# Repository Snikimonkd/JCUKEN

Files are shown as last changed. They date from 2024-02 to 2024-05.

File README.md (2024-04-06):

# JCUKEN

Cyrillic-friendly low profile ortholinear split keyboard.

## Tools

Designed with [ergogen](https://github.com/ergogen/ergogen).

Routed with [KiCad](https://www.kicad.org/).

## Version 1

### Top view

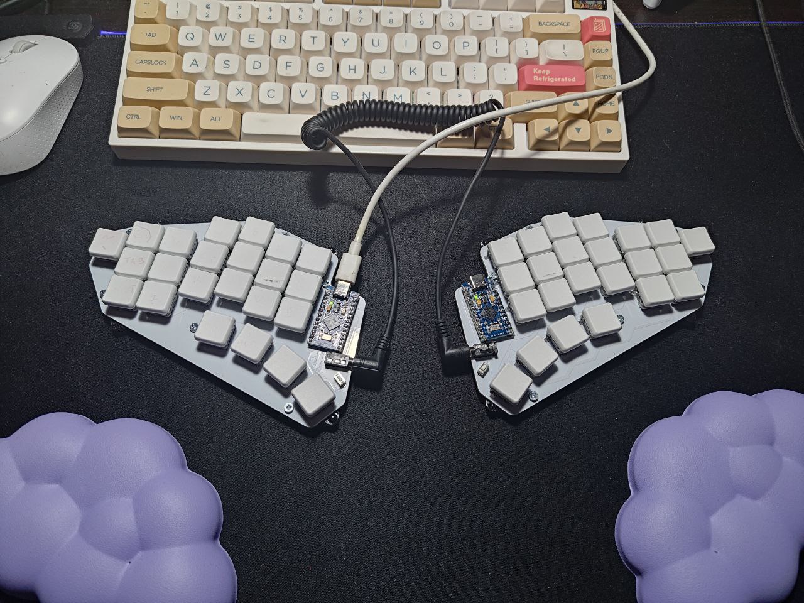
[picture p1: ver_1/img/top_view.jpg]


### Close up view

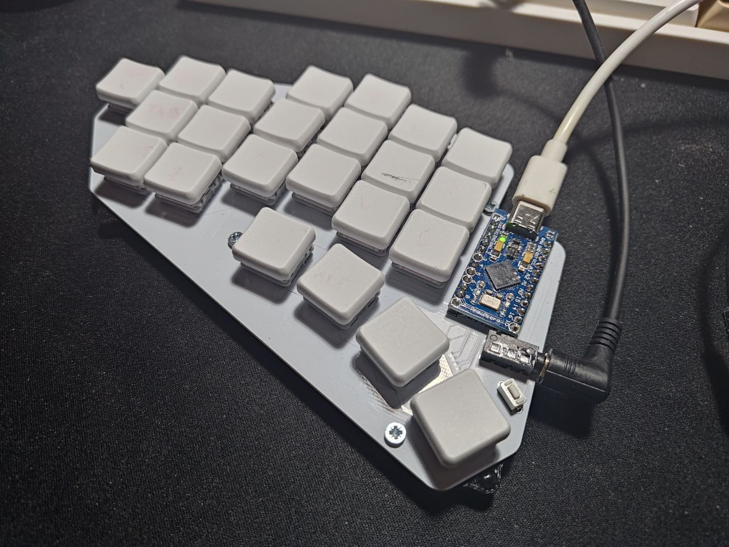
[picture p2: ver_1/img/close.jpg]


### High stands

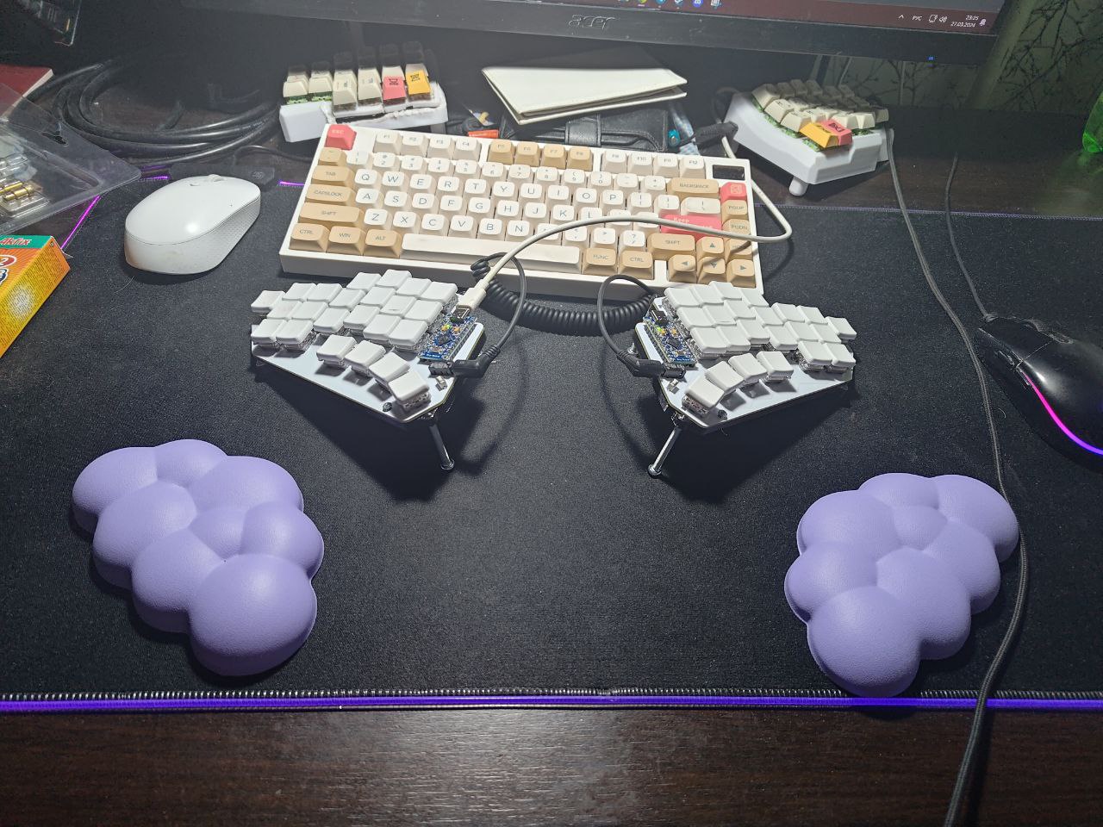
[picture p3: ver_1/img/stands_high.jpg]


### Low stands

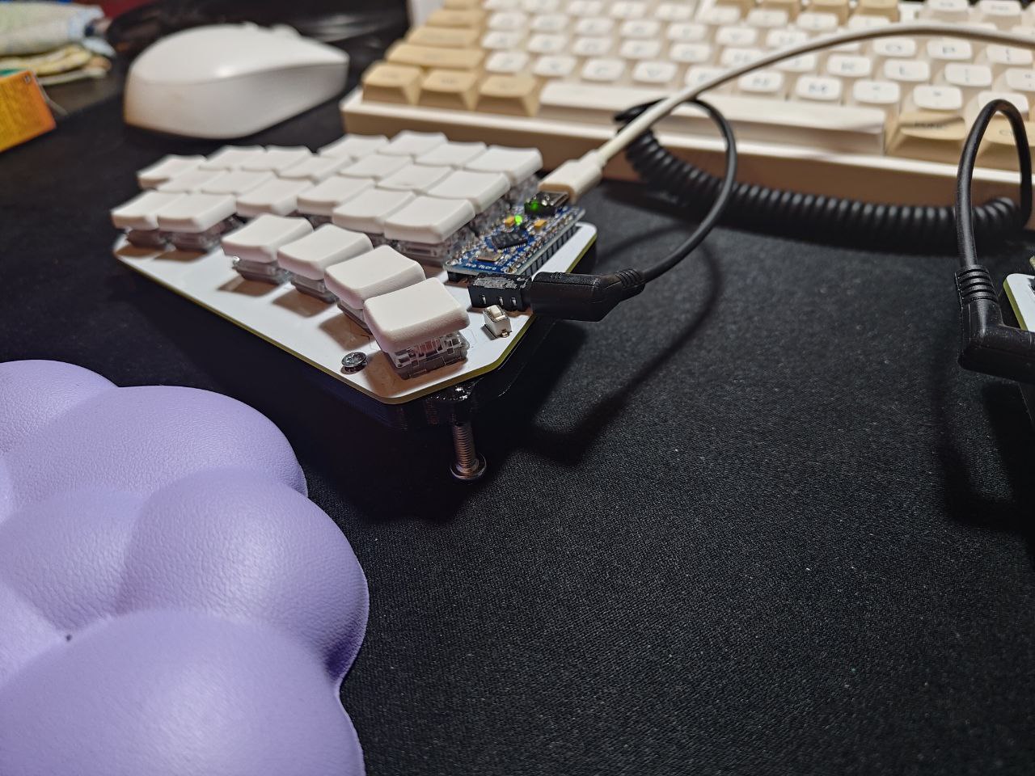
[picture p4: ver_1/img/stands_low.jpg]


## Materials

| Part | Link | Price |
| --- | --- | --- |
| PCB (5 pcs) | [link](https://aliexpress.ru/store/1100324072?g=y&page=1&searchInfo=search) | 25$ |
| ProMicro (2 pcs) | [link](https://aliexpress.ru/item/1005005787284179.html) | 5$ |
| Diods (100 pcs) | [link](https://aliexpress.ru/item/1005006043982096.html) | 1$ |
| Reset buttons (100 pcs) | [link](https://aliexpress.ru/item/4000533166385.html) | 1$ |
| TRRS cable | [link](https://aliexpress.ru/item/1005003415667083.html) | 2$ |
| Switches (70 pcs) | [link](https://aliexpress.ru/item/1005005883472162.html) | 27$ |
| TRRS connectors (10 pcs)  | [link](https://aliexpress.ru/item/1005003299392377.html) | 1$ |
| Hot swap sockets (70 pcs) | [link](https://aliexpress.ru/item/1005006007846154.html) | 10$ |
| Keycaps (50pcs) | [link](https://aliexpress.ru/item/1005004558099208.html) | 22$ |
| Case | [link](https://github.com/Snikimonkd/JCUKEN/tree/main/case) | 2$ (3 beers for my buddy) |
| Bolts/Stands (10 pcs) | Local hardware store | 1$ |
| **Total** | | **~97$** |

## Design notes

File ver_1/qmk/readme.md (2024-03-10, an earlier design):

# jcuken

jcuken

*A short description of the keyboard/project*

* Keyboard Maintainer: [Snikimonkd](https://github.com/Snikimonkd)
* Hardware Supported: *The PCBs, controllers supported*
* Hardware Availability: *Links to where you can find this hardware*

Make example for this keyboard (after setting up your build environment):

    make jcuken:default

Flashing example for this keyboard:

    make jcuken:default:flash

See the [build environment setup](https://docs.qmk.fm/#/getting_started_build_tools) and the [make instructions](https://docs.qmk.fm/#/getting_started_make_guide) for more information. Brand new to QMK? Start with our [Complete Newbs Guide](https://docs.qmk.fm/#/newbs).

## Bootloader

Enter the bootloader in 3 ways:

* **Bootmagic reset**: Hold down the key at (0,0) in the matrix (usually the top left key or Escape) and plug in the keyboard
* **Physical reset button**: Briefly press the button on the back of the PCB - some may have pads you must short instead
* **Keycode in layout**: Press the key mapped to `QK_BOOT` if it is available

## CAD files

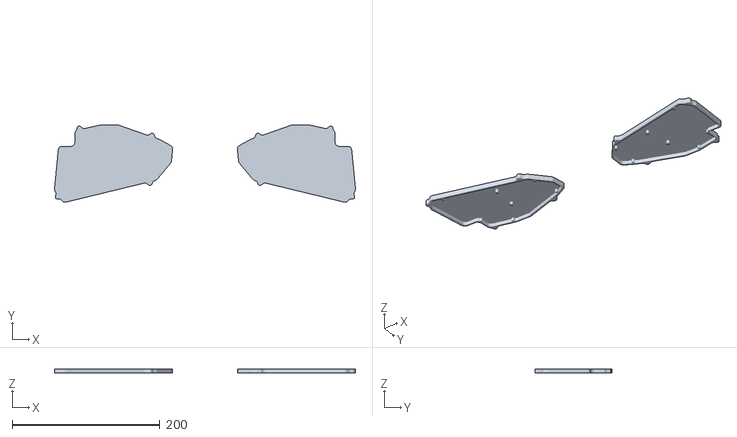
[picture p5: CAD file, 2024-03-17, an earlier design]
ver_1/case/case.stl
408.1 x 105.0 x 6.00

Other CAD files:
ver_1/case/case.ipt

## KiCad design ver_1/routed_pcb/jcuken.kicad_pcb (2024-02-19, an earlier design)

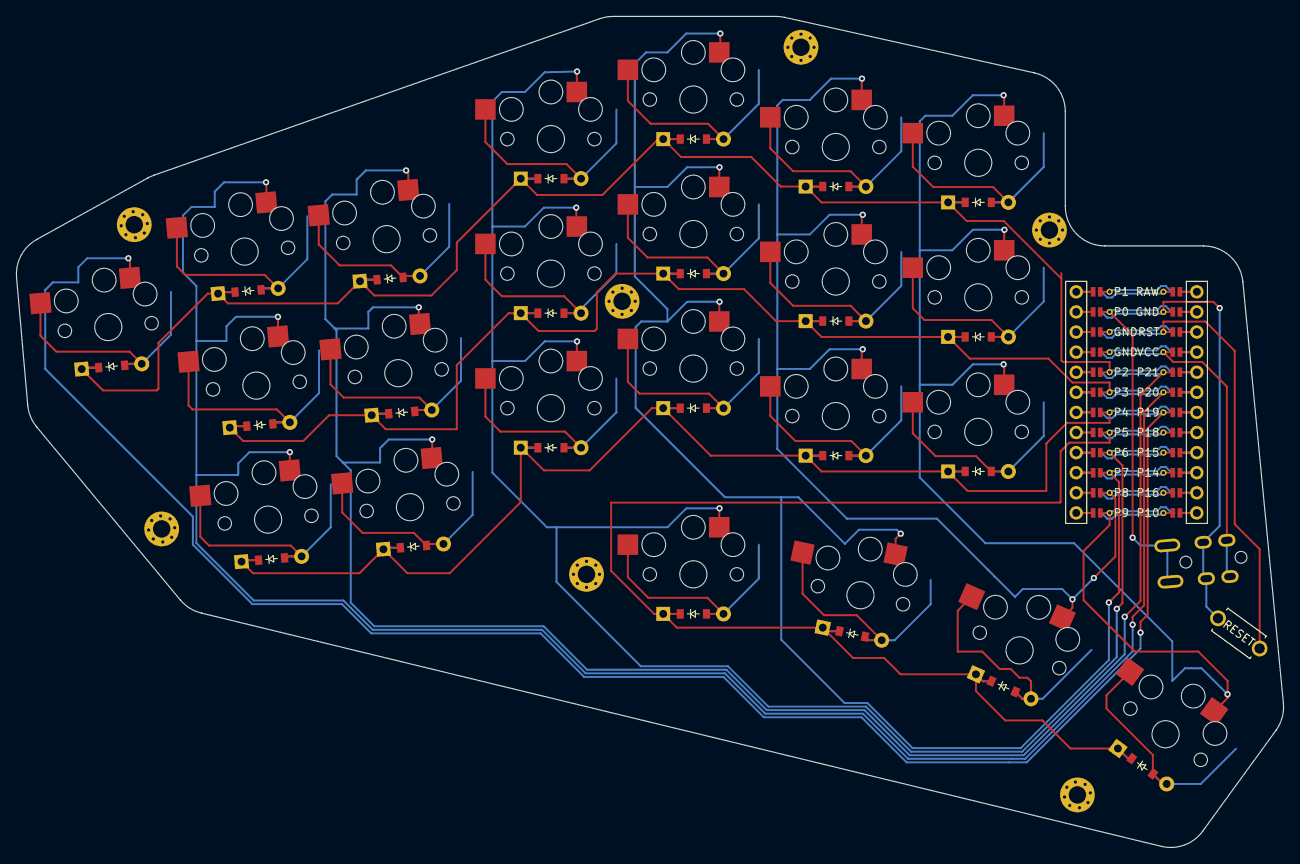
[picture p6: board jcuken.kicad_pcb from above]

Board: 2 copper layers, 160.1 x 105.0 mm, 56 parts (0 on the bottom side), 50 nets.

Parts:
B1: ResetSW
D1, D2, D3, D4, D5, D6, D7, D8, D9, D10, D11, D12, D13, D14, D15, D16, D17, D18, D19, D20, D21, D22, D23: ComboDiode
MCU1: nice_nano
S1, S2, S3, S4, S5, S6, S7, S8, S9, S10, S11, S12, S13, S14, S15, S16, S17, S18, S19, S20, S21, S22, S23: PG1350
TRRS1: TRRS-PJ-320A-dual; trrs_pj320a (reversible, symmetric)
_1, _2, _3, _4, _5, _6, _7: MountingHole_2.2mm_M2_Pad_Via

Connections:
GND: B1.2, MCU1.2, TRRS1.2
MCU1_1: MCU1.1, MCU1.24
MCU1_2: MCU1.2, MCU1.23
MCU1_3: MCU1.3, MCU1.22
MCU1_4: MCU1.4, MCU1.21
MCU1_5: MCU1.5, MCU1.20
MCU1_6: MCU1.6, MCU1.19
MCU1_7: MCU1.7, MCU1.18
MCU1_8: MCU1.8, MCU1.17
MCU1_9: MCU1.9, MCU1.16
MCU1_10: MCU1.10, MCU1.15
MCU1_11: MCU1.11, MCU1.14
MCU1_12: MCU1.12, MCU1.13
P0: MCU1.123, TRRS1.1
P2: D1.1, D4.1, D7.1, D10.1, D13.1, D16.1, D19.1, MCU1.120
P3: D3.1, D6.1, D9.1, D12.1, D15.1, D18.1, MCU1.119
P4: D2.1, D5.1, D8.1, D11.1, D14.1, D17.1, MCU1.118
P5: D20.1, D21.1, D22.1, D23.1, MCU1.117
P6: MCU1.116, S8.1, S9.1, S10.1, S20.1
P7: MCU1.115, S11.1, S12.1, S13.1, S21.1
P8: MCU1.114, S14.1, S15.1, S16.1, S22.1
P9: MCU1.113, S17.1, S18.1, S19.1, S23.1
P19: MCU1.7, S1.1
P20: MCU1.6, S2.1, S3.1, S4.1
P21: MCU1.5, S5.1, S6.1, S7.1
RST: B1.1, MCU1.3
VCC: MCU1.4, TRRS1.3
far_outer_top: D1.2, S1.2
far_thumb: D23.2, S23.2
home_thumb: D21.2, S21.2
index_bottom: D14.2, S14.2
index_home: D15.2, S15.2
index_top: D16.2, S16.2
inner_bottom: D17.2, S17.2
inner_home: D18.2, S18.2
inner_top: D19.2, S19.2
middle_bottom: D11.2, S11.2
middle_home: D12.2, S12.2
middle_top: D13.2, S13.2
near_thumb: D20.2, S20.2
one_more_thumb: D22.2, S22.2
outer_bottom: D2.2, S2.2
outer_home: D3.2, S3.2
outer_top: D4.2, S4.2
pinky_bottom: D5.2, S5.2
pinky_home: D6.2, S6.2
pinky_top: D7.2, S7.2
ring_bottom: D8.2, S8.2
ring_home: D9.2, S9.2
ring_top: D10.2, S10.2

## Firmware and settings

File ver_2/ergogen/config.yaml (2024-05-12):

meta:
  engine: 4.1.0
  version: 0.1
  author: snikimonkd
units:
  # Proxy Spacing Variables
  kx: u
  ky: u
  # Padding Variables
  padding: 4
  # will be devided by 2
  outer_padding: 8
  inner_padding: 8
  px: kx + padding
  py: ky + padding
  opx: px+outer_padding
  opy: py+outer_padding
  ipx: px-inner_padding
  ipy: py-inner_padding
  # circles
  top_radius: 180
  outer_top_radius: top_radius+outer_padding/2
  inner_top_radius: top_radius-inner_padding/2
  # thumb shift
  thumb_x: 8
  thumb_y: -26
  # MCU size
  mcu_width: 17
  mcu_height: 33
points:
  zones:
    matrix:
      anchor:
        shift: [50, -100]
      key:
        padding: 1ky
        spread: 1kx
      rows:
        bot:
          row_net: P4 #21
        home:
          row_net: P3 #20
        top:
          row_net: P2 #19
      columns:
        inner:
          key:
            column_net: P9 #18
            stagger: -2
        index:
          key:
            column_net: P8 #15
            stagger: -4
        middle:
          key:
            column_net: P7 #14
            stagger: 4
        ring:
          key:
            column_net: P6 #16
            origin: [-12, -10]
            stagger: 4
        pinky:
          key:
            column_net: P21 #10
            stagger: 3
        outer:
          key:
            column_net: P20 #9
    thumbfan:
      anchor:
        ref: matrix_index_bot
        shift: [thumb_x, thumb_y]
      columns:
        near:
          key:
            column_net: P8 #8
            shift: [0, 0]
        home:
          key:
            column_net: P9 #7
            shift: [4, -2]
            splay: -18
      rows:
        thumb:
          row_net: P5

    top_left:
      anchor:
        ref: matrix_outer_top
        shift: [-0.5px, 0.5py]
    top_right:
      anchor:
        - ref: matrix_inner_top
          shift: [0.5px,0.5py]
    bot:
      anchor:
        aggregate:
          parts:
            - ref: thumbfan_home_thumb
            - ref: thumbfan_near_thumb
        orient: thumbfan_near_thumb

  rotate: 0

outlines:
  keys:
    - what: rectangle
      where: [/^matrix_.*/,/^thumbfan.*/]
      size: [kx-0.5,ky-0.5]

  mcu:
    - what: rectangle
      where:
        ref: matrix_inner_bot
        shift: [0.5px+mcu_width/2, 0.5py]
      size: [mcu_width,mcu_height]

  circle_top:
    - what: circle
      radius: top_radius
      where:
        aggregate:
          parts:
            - ref: top_left
            - ref: top_right
        orient: top_left
        shift: [-171,0]

  outer_circle_top:
    - what: circle
      radius: outer_top_radius
      where:
        aggregate:
          parts:
            - ref: top_left
            - ref: top_right
        orient: top_left
        shift: [-171,0]

  inner_circle_top:
    - what: circle
      radius: inner_top_radius
      where:
        aggregate:
          parts:
            - ref: top_left
            - ref: top_right
        orient: top_left
        shift: [-171,0]

  body_stairs:
    - what: polygon
      points:
        - ref: matrix_outer_top
          shift: [-0.5px,0.5py+15]
        - ref: matrix_inner_top
          shift: [0.5px,0.5py+15]
        - ref: matrix_inner_home
          shift: [0.5px,0.5ky]
        - ref: matrix_inner_home
          shift: [0.5px+mcu_width+padding/2,0.5ky]
        - ref: matrix_inner_home
          shift: [0.5px+mcu_width+padding/2,0.5ky-mcu_height-padding-10]
        - ref: thumbfan_home_thumb
          shift: [0.5px+5,-0.5py]
        #
        - ref: bot
          shift: [-0.5px+1.5, 0]
        #
        - ref: thumbfan_near_thumb
          shift: [-0.5px,-0.5py]
        - ref: thumbfan_near_thumb
          shift: [-0.5px,-thumb_y-0.5py]
        - ref: matrix_index_bot
          shift: [-0.5px,-0.5py]
        - ref: matrix_middle_bot
          shift: [kx-0.5px,-0.5py]
        - ref: matrix_middle_bot
          shift: [-kx+0.5px,-0.5py]
        - ref: matrix_ring_bot
          shift: [0.5px,-0.5py]
        - ref: matrix_ring_bot
          shift: [-kx+0.5px,-0.5py]
        - ref: matrix_pinky_bot
          shift: [0.5px,-0.5py]
        - ref: matrix_pinky_bot
          shift: [-kx+0.5px,-0.5py]
        - ref: matrix_outer_bot
          shift: [0.5px,-0.5py]
        - ref: matrix_outer_bot
          shift: [-0.5px,-0.5py]
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

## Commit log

2024-03-17 add routed pcb
    [jcuken.kicad_pcb]
2024-03-20 add case to readme
2024-04-06 version 2 start
    [case.ipt, case.stl, jcuken.kicad_pcb]
2024-04-06 some fixes to v2
    [config.yaml]
2024-04-20 change everything
    [outline.dxf, outline.ipt, outlines.ipt]
2024-04-30 fix pcbs
2024-05-11 update footprints + finish board
    [outline.dxf, outline.ipt, outlines.ipt]
2024-05-12 update footprints
